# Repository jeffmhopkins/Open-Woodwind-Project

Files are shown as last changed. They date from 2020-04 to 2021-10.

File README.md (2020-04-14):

# Open-Woodwind-Project

The Open Woodwind Project is aimed at making an open source MIDI Woodwind Controller with onboard synthesizer.

It utilizes a Teensy microcontroller with Audio Breakout, two MPR121s,BNO055 IMU, and MPXV4006GP pressure Transducer. 

OWP_Synth is a sub project utilizing a Teensy Audio Libray based multi oscillator with LFOs, waveshaping, effects, and a complex modulation scheme, controlled over an OSC iPad interface. It will eventually be fully integrated into the onboard synth for the controller.  

The OWP_Synth relies heavily on a TouchOSC interface to control it. This requires an OSC to MIDI bridge. On Windows you can use TouchOSC MIDI bridge, but for linux there's no offering from the TouchOSC developers, so it's a bit more complicated to setup, but all the config files and packages are called out for, and you should be able to get it setup if you want. See https://github.com/jeffmhopkins/Open-Woodwind-Project/tree/master/src/osc_configuration_for_linux_touchosc readme for how to do this.

See https://hackaday.io/project/2992-the-open-woodwind-project for porject log information.

I'll be including source code, and the 3D printing files necessary to reproduce this project in full here.

Jeff

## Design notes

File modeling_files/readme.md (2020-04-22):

# Modeling Files

* Teensy Box - Files for the standalone Teensy 4.0 + Audio Board Rev D
* Instrument - Files for the new OWP instrument

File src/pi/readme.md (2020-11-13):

# Setup Pi for powering on
* Ensure SD card is fully inserted
* Ensure USB Audio interface (the one that came taped to the case) is plugged in to front of Pi (I usually plug it in the middle bottom USB)
* Plug in the Pocket Synth into the front USB
* Plug in your MIDI controller to the front USB
* Plug in the DC power supply to mains voltage
* Plug in the micro USB into the Pi, it’ll start powering on
# Configure iPad
* Power on iPad, ensure you have TouchOSC and VNC installed
* Connect to the ‘OpenSynth’ WiFi network, password is ‘OpenSynth’
* * The WiFi network defaults to DHCP, so IP address should automatically be assigned (in the 10.10.10.X range)
* * It might take a minute to actually connect and assign an IP address, so give it some time.
* Launch VNC and connect to ’10.10.10.10’ username ‘pi’ password ‘OpenSynth’
# Configure Pi
* The Pi uses Jack to control MIDI patching. Once a Patchbay is saved, it will automagically patch your devices as they are plugged in. The Jack control interface is auto launched at power up. 
* Click on ‘Patch Bay’ in the Jack control interface
* Patch your MIDI controller to match the routing of the ‘Open Woodwind’
* SCREENSHOT GOES HERE
* Save the patch bay and make sure it’s ‘active’
# Test setup
* At this point you should be able to play notes and have the MIDI stream into the Pocket Synth, this can be verified with headphones from the OpenSynth headphone output.
# Configure TouchOSC
* You must transfer the TouchOSC interface to the iPad. File can be found here: https://github.com/jeffmhopkins/Open-Woodwind-Project/blob/master/src/osc_configuration_for_linux_touchosc/osc2midi.omm
* In TouchOSC configure the interface to connect to send OSC messages to 10.10.10.10:3333 and listen on port 3334
# At this point the TouchOSC interface on the iPad should be receiving OSC messages from the Pi. Breath, etc should be visibly changing with your controller values.
* Play and have fun controlling the Synth from the TouchOSC interface
# Shutdown the Pi
* Log into pi via VNC, hit the main menu button and ‘shutdown’
* If you just unplug the USB power, it will work, but you risk corrupting the SD card (I’ve not had this happen even multiple ‘hard shutdowns’ but I try to not to do it)

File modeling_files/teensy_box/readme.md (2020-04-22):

# Files for a box to hold the Teensy 4.0 + Audio Boad Rev D

Notes:
* The Teensy is meant to be soldered directly to the top of the audio board, using male pin headers. One of the capacitors on the Teensy comes VERY close to the SD card slot. Insulate the top of the SD card slot with kapton tape to avoid shorting.
* The Audio board is secured to the box with three 6mm M3 screws. The board fits TIGHT to the interior of the box. You have to insert the USB and headphone jack, and press fit it down into the box.
* If the board is too tight, you may have to inset the model in your slicer (My printer and your printer are likely a little different)
* The bumper is meant to be printed with the modeled supports in TPU. The modeled supports have a 0.3mm gap, which when you slice should be a ONE LAYER gap. adjust your settings to make this true, and your supports will come out great.

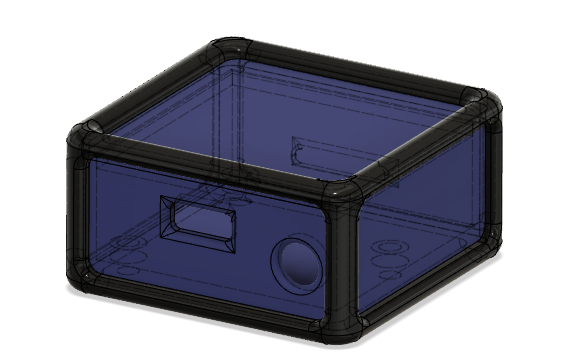
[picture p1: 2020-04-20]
modeling_files/teensy_box/Box.PNG

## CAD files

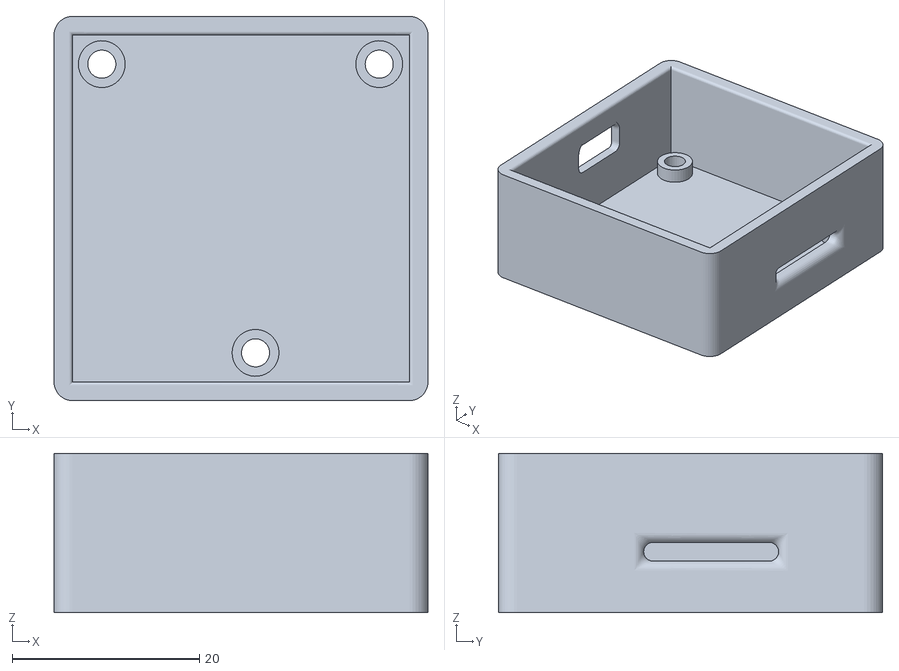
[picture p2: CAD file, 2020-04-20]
modeling_files/teensy_box/Teensy_Box_Box.stl
39.9 x 41.0 x 17.0

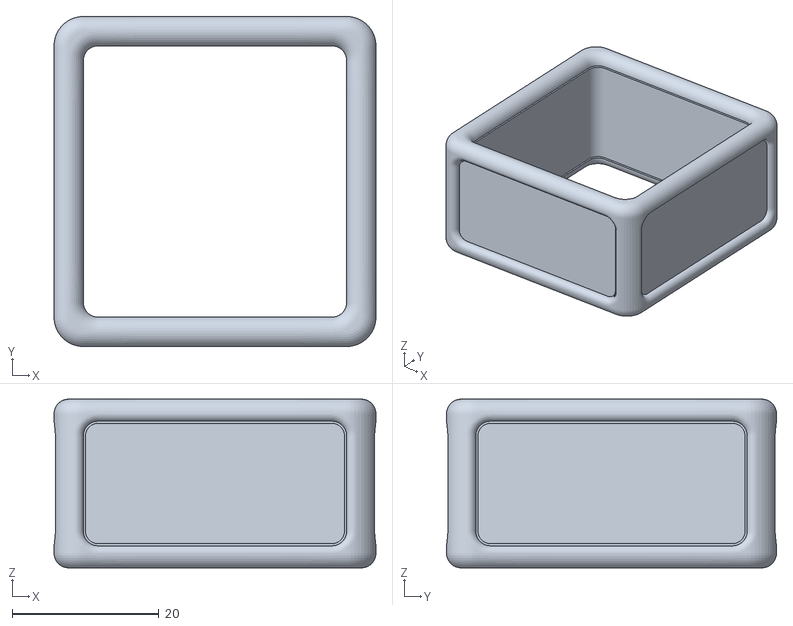
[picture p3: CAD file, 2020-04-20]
modeling_files/teensy_box/Teensy_Box_Bumper_With_Supports.stl
43.9 x 45.0 x 23.0

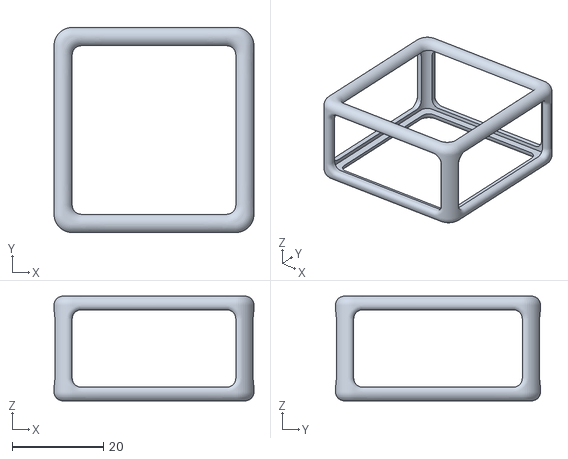
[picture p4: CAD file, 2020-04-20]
modeling_files/teensy_box/Teensy_Box _Bumper_No_Supports.stl
43.9 x 45.0 x 23.0

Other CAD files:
modeling_files/instrument.f3d

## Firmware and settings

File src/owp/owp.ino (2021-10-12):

/*
    This program is free software: you can redistribute it and/or modify
    it under the terms of the GNU General Public License as published by
    the Free Software Foundation, either version 3 of the License, or
    (at your option) any later version.
    This program is distributed in the hope that it will be useful,
    but WITHOUT ANY WARRANTY; without even the implied warranty of
    MERCHANTABILITY or FITNESS FOR A PARTICULAR PURPOSE.  See the
    GNU General Public License for more details.
    You should have received a copy of the GNU General Public License
    along with this program.  If not, see <https://www.gnu.org/licenses/>.
*/


/*

The Open Woodwind Project uses the following components:
  Teensy 3.2
  MPR121 (address 0x5A)
  MPR121 (address 0x5B)
  MPX2010GS (going into A0, a few filtering caps installed)
  BNO055
  
  It should be compiled in the Teensy Arduino environment with MIDI + SERIAL board options.

*/

#include <Wire.h>
#include <SPI.h>
#include "Adafruit_MPR121.h"
#include <Adafruit_Sensor.h>
#include <Adafruit_BNO055.h>
#include <utility/imumaths.h>

#define STATE_NOTE_OFF 0
#define STATE_NOTE_NEW 1
#define STATE_NOTE_ON  2

#define SETTINGS_NOTE_DEBOUNCE_DELAY 20
#define SETTINGS_BREATH_AVERAGING    0.7f
#define SETTINGS_BREATH_GAIN         3.0f
#define SETTINGS_BREATH_THRESHOLD    225
#define SETTINGS_CC_DELAY            0
#define SETTINGS_LEGATO              true
#define SETTINGS_TOUCH_LEVEL         100

#define IMU_RAISE  0
#define IMU_LOWER  1
#define IMU_CENTER 2
#define IMU_CC_POSITIVE false
#define IMU_CC_NEGATIVE true

#define CONTROLLER_MODE_MIDI    0
#define CONTROLLER_MODE_MODULAR 1
#define CONTROLLER_MODE_TRIGGER 2
#define CONTROLLER_SET_CCW_OFF  3
#define CONTROLLER_SET_CCW_EXPRESSION 4
#define CONTROLLER_SET_MOD_WHEEL_OFF 5
#define CONTROLLER_SET_MOD_WHEEL_ON  6
#define CONTROLLER_SET_BREATH_ON 7
#define CONTROLLER_SET_BREATH_OFF 8

#define CCW_MODE_OFF        0
#define CCW_MODE_EXPRESSION 1

int trigger_min_velocity = 10;

int state = STATE_NOTE_OFF;

int  note_temp              = 0;                    //Temporary variable used during legato fingering 
int  note_playing           = 0;                    //The MIDI note of the current note being played
int  note_fingered          = 0;                    //The MIDI note of the current note being fingered
bool note_debounce          = false;                //Whether or not we are in debounce wait
long note_debounce_time     = 0;                    //The millis() at time of finger change, start of debounce 
int  note_fingered_debounce = 0;                    //The MIDI note of the current note being fingered during debounce wait
int  note_debounce_delay    = SETTINGS_NOTE_DEBOUNCE_DELAY; //How long to wait in debounce before committing to finer change

int   breath_sent      = 0;                         //The last CC breath message value
int   breath_measured  = 0;                         //Current measured breath
float breath_averaging = SETTINGS_BREATH_AVERAGING; //Percent of new vs old breath
int   breath_threshold = SETTINGS_BREATH_THRESHOLD; //The threshold for breath to trigger a note
long  breath_time      = 0;                         //The millis() at time of threshold breach
int   breath_risetime  = 5;                         //the delay after threshold breach before sampling breath for the first CC message

long  cc_time  = 0;                                 //The millis() at time of last CC send
int   cc_delay = SETTINGS_CC_DELAY;                 //Delay in ms between CC messages

bool  legato = SETTINGS_LEGATO;                     //Legato fingering mode

float deg_y           = 0.0;                        //The angle of the instrument
float deg_y_averaging = 0.5;                        //Smoothing from last loop's poll

float deg_z           = 0.0;                        //The roll of the instrument
float deg_z_averaging = 0.5;                        //Smoothing from last loop's poll

float accel           = 0.0;		                    //Accelerometer data
float accel_averaging = 0.5;                        //Smoothing from last loop's poll
float accel_damping   = 1.5;		                    //Accelerometer dampening

float imu_deg_init    = 0.0;                        //Placeholder for when we gate our pb buttons, locking in the current instrument angle 
float imu_up_limit    = -40;		                    //The up angle for modulation
float imu_down_limit  = -60;		                    //The down angle for modulation

float imu_roll_deadband    = 25;			              //How wide our roll dead band is
float imu_roll_upper_limit = 30;	                  //Upper roll limit
float imu_roll_lower_limit = -30;		                //Lower roll limit
boolean imu_roll_active    = false;		              //Is imu roll active

float imu_pb_deg_init   = 0.0;						
float imu_pb_up_limit   = 15;
float imu_pb_down_limit = -15;
float imu_pb_deadband   = 6.0;
bool  imu_pb_active     = false;

bool  settings_mode_fingered = false;
int   controller_return_mode = 0;


//THESE ARE THE DEFAULT SETTINGS
int   controller_mode = CONTROLLER_MODE_MODULAR;
int   ccw_mode = CCW_MODE_OFF; //CCW_MODE_EXPRESSION
bool  mod_wheel_enabled = true;
bool  breath_enabled = false; //when setting to midi mode this comes on automatically, and modular turns it off

Adafruit_MPR121 touchA = Adafruit_MPR121();	      //Actual MPR121 object
Adafruit_MPR121 touchB = Adafruit_MPR121();			
Adafruit_BNO055 bno = Adafruit_BNO055(55);	      //IMU	
sensors_event_t event;				                    //IMU event object

bool A[] = {false,false,false,false,false,false,false,false,false,false,false,false}; // These are the arrays for finger positions
bool B[] = {false,false,false,false,false,false,false,false,false,false,false,false};

bool A_last[] = {false,false,false,false,false,false,false,false,false,false,false,false}; // These are the arrays for finger positions
bool B_last[] = {false,false,false,false,false,false,false,false,false,false,false,false};

long A_debounce[] = {0,0,0,0,0,0,0,0,0,0,0,0};
long B_debounce[] = {0,0,0,0,0,0,0,0,0,0,0,0};

int CC[128]; 					      //CC array
int pb = 0;					        //pb value

const int ledPin = 13;			//LED for noteOn (onboard Teensy)

float ambient_breath_reading = 0;


void setup() {
  for(int i = 0; i < 128; i++) {
    CC[i] = 0;
  }
  touchA.begin(0x5A);
  touchB.begin(0x5B);
  if(!bno.begin())
  {
    /* There was a problem detecting the BNO055 ... check your connections */
    Serial.print("Ooops, no BNO055 detected ... Check your wiring or I2C ADDR!");
    while(1);
  }
  delay(1000);
  bno.setExtCrystalUse(true);
  pinMode(ledPin, OUTPUT);

  ambient_breath_reading = SETTINGS_BREATH_GAIN * analogRead(A0);
  if(ambient_breath_reading > 1023) ambient_breath_reading = 1023;
}
  
void loop() {
  // Update our breath, fingered note, and CC messages
  updateSensors();
  if(cc_delay == 0) {
    sendCC();
  } else {
    if(millis() > cc_time + cc_delay) {
      sendCC();
      cc_time = millis();
    }
  }
  //Check for settings beings changed
  if(controller_mode == CONTROLLER_SET_CCW_OFF)        {ccw_mode = CCW_MODE_OFF;        controller_mode = controller_return_mode;}
  if(controller_mode == CONTROLLER_SET_CCW_EXPRESSION) {ccw_mode = CCW_MODE_EXPRESSION; controller_mode = controller_return_mode;}
  if(controller_mode == CONTROLLER_SET_MOD_WHEEL_ON)   {mod_wheel_enabled = true;       controller_mode = controller_return_mode;}
  if(controller_mode == CONTROLLER_SET_MOD_WHEEL_OFF)  {mod_wheel_enabled = false;      controller_mode = controller_return_mode;}
  if(controller_mode == CONTROLLER_SET_BREATH_ON)      {breath_enabled    = true;       controller_mode = controller_return_mode;}
  if(controller_mode == CONTROLLER_SET_BREATH_OFF)     {breath_enabled    = false;      controller_mode = controller_return_mode;}

  //Change Controller Modes, or goto the current 
  if(controller_mode == CONTROLLER_MODE_MIDI) {
    if(controller_return_mode != CONTROLLER_MODE_MIDI) breath_enabled = true;  
    stateMachineControllerMidi();   
  }
  if(controller_mode == CONTROLLER_MODE_MODULAR) {
    if(controller_return_mode != CONTROLLER_MODE_MODULAR) breath_enabled = false; 
    stateMachineControllerModular();
  }
  if(controller_mode == CONTROLLER_MODE_TRIGGER) {
    stateMachineControllerTrigger();
  }
  
  while (usbMIDI.read()) {
    // ignore incoming messages
  }
}

void stateMachineControllerMidi() {
    if(state == STATE_NOTE_OFF) {
      if(breath_measured > breath_threshold) {
        breath_time = millis();
        state = STATE_NOTE_NEW;
      }
    }
    if(state == STATE_NOTE_NEW) {
      if(settings_mode_fingered) {
        setSettings();
      } else {
         if(breath_measured > breath_threshold) {
           if(millis() > breath_time + breath_risetime) {
             sendCC();
             sendNoteOn(note_fingered);
             cc_time = millis();
             digitalWrite(ledPin, HIGH);
             state = STATE_NOTE_ON;
          }
        } else {
          state = STATE_NOTE_OFF;
        }
      }
    }
    if((state == STATE_NOTE_ON) & (!settings_mode_fingered)) {
      if(breath_measured > breath_threshold) {
        if(note_fingered != note_playing) {
          if(legato) {
            note_temp = note_playing;
            if(imu_pb_active) {
              imu_pb_deg_init = deg_y;
              usbSendPitchBend(0, 1);
            }
            sendNoteOn(note_fingered);
            sendNoteOff(note_temp);
          } else {
            sendNoteOff(note_playing);
            sendNoteOn(note_fingered);
          }
        }
      } else {
        if(!settings_mode_fingered) {
          sendNoteOff(note_playing);
          digitalWrite(ledPin, LOW);
          state = STATE_NOTE_OFF;
        }
      }
    }
}

void stateMachineControllerModular() {
  if(settings_mode_fingered) {
    updateBreath();
    if(breath_measured > breath_threshold) {
      setSettings();
    } 
  } else {
    if(note_fingered != note_playing) {
      if(legato) {
        note_temp = note_playing;
        if(imu_pb_active) {
          imu_pb_deg_init = deg_y;
          usbSendPitchBend(0, 1);
        }
        sendNoteOn(note_fingered);
        sendNoteOff(note_temp);
      } else {
        sendNoteOff(note_playing);
        sendNoteOn(note_fingered);
      }
    }
  }
}

void stateMachineControllerTrigger() {
  int b = map(breath_measured,SETTINGS_BREATH_THRESHOLD,1023,0,127);
  float d= deg_y;
  if(d < imu_down_limit) d = imu_down_limit;
  if(d > imu_up_limit)   d = imu_up_limit;
  int velocity = (int)mapf(d, imu_down_limit, imu_up_limit, trigger_min_velocity, 127);
   
  if(b>64) {
    if(B[0] & !B[1] & B[2]) {
      settings_mode_fingered = true;
    } else {
      settings_mode_fingered = false;
    }
    if(settings_mode_fingered) {
      setSettings();
    }
  }
  for (uint8_t i=0; i<12; i++) {
    A_last[i] = A[i];
    B_last[i] = B[i];
    A[i] = touchA.filteredData(i) < SETTINGS_TOUCH_LEVEL;
    B[i] = touchB.filteredData(i) < SETTINGS_TOUCH_LEVEL;
  }
  int trigger_offset = 0;
  if( B[0] &!B[1])         trigger_offset -= 24;  // bottom left
  if( B[0] & B[1])         trigger_offset -= 12;  // bottom left mid left bridged
  if( B[1] & B[2])         trigger_offset += 12;  // mid left top left bridged
  if(!B[1] & B[2])         trigger_offset += 24;  // top left
  for(int i = 0; i < 12; i++) {
    //bass drum on 36
    if(A_last[i] != A[i]) A_debounce[i] = millis() + 10;
    if((millis() > A_debounce[i]) && A_debounce[i] != 0) {
       if(!A[i]) sendNoteOff(36 + i + trigger_offset);
       if(A[i])  sendNoteOn(36 + i + trigger_offset, velocity);
       A_debounce[i] = 0;
    }
  }
  
}

void setSettings() {
   if(A[0]) controller_mode = CONTROLLER_MODE_MIDI;    // A[0] = Left Hand Index
   if(A[1]) controller_mode = CONTROLLER_MODE_MODULAR; // A[1] = Left Hand Middle
   if(A[2]) controller_mode = CONTROLLER_MODE_TRIGGER; // A[2] = Left Hand Ring
   if(A[3]) {controller_return_mode = controller_mode; controller_mode = CONTROLLER_SET_CCW_OFF;}
   if(A[4]) {controller_return_mode = controller_mode; controller_mode = CONTROLLER_SET_CCW_EXPRESSION;}
   if(A[5]) {controller_return_mode = controller_mode; controller_mode = CONTROLLER_SET_MOD_WHEEL_OFF;}
   if(A[6]) {controller_return_mode = controller_mode; controller_mode = CONTROLLER_SET_MOD_WHEEL_ON;}
   if(A[7]) {controller_return_mode = controller_mode; controller_mode = CONTROLLER_SET_BREATH_OFF;}
   if(A[8]) {controller_return_mode = controller_mode; controller_mode = CONTROLLER_SET_BREATH_ON;}
   
         // A[5] = Right Hand Index
         // A[6] = Right Hand Middle
         // A[7] = Right Hand Ring
}

void updateSensors() {
  updateBreath();
  if(controller_mode != CONTROLLER_MODE_TRIGGER) updateNote();
  updateCC();
}

void updateBreath() {
  float value = SETTINGS_BREATH_GAIN * analogRead(A0);
  if(value>1023) value = 1023;
  breath_measured = value; //breath_averaging * value + (1.0f - breath_averaging) * breath_measured;
}

void updateNote() {
  note_fingered_debounce = 60 + parseNote(); //Update from capacitive touch board
  if(note_fingered_debounce != note_fingered) {
    if(note_debounce) {
      if(millis() > note_debounce_time + note_debounce_delay) {
        note_fingered = note_fingered_debounce;
        note_debounce = false;
      }
    } else {
      note_debounce_time = millis();
      note_debounce = true;
    }
  }
}

int parseNote() {
	// Mapping as follows: 
	// A[0] = Left Hand Index
	// A[1] = Left Hand Middle
	// A[2] = Left Hand Ring
	// A[3] = Left Hand Pinky 1 (sharp)
	// A[4] = Left Hand Pinky 2 (flat)
	// A[5] = Right Hand Index
	// A[6] = Right Hand Middle
	// A[7] = Right Hand Ring
	// A[8] = Right Hand Pinky 1 (Sharp)
	// A[9] = Right Hand Pinky 2 (Flat)
	// A[10]= Right Hand Pinky 3 (Double Flat)
	// B[0] = Bottom Octave (Left thumb bottom)
	// B[1] = Middle Octave (Left thumb mid)
	// B[2] = Top Octave    (Left thumb top)
	// B[3] = PB gate 
	// B[4] = PB gate
	// B[5] = PB Gate
	//
  for (uint8_t i=0; i<12; i++) {
    A[i] = touchA.filteredData(i) < SETTINGS_TOUCH_LEVEL;
    B[i] = touchB.filteredData(i) < SETTINGS_TOUCH_LEVEL;
  }

  //Check Settings mode
  if(B[0] & !B[1] & B[2]) {
    settings_mode_fingered = true;
  } else {
    settings_mode_fingered = false;
  }

  //Determine Register
  bool rh = !A[0] & A[1] & !A[2] & A[5];
  bool rl = !A[5] & A[6] &  A[7] & A[10];
  bool rm = !rh & !rl;

  int note = 13;

  if(rm) {
    if( A[0] & !A[1]) note -= 2;
    if(!A[0] &  A[1]) note -= 1;
    if( A[0] &  A[1]) note -= 4;
    if(A[2]) note -= 2;
    if(A[5]) note -= 2;
    if(A[6]) note -= 1;
    if(A[7]) note -= 2;
  }
  if(rh) {
    note = 17;
    if(A[6]) note -= 1;
    if(!A[5] & A[6]) note += 2;
    if(A[7]) note -= 2;
  }
  if(rl) {
     note = 3;
     if(A[0] & !A[1]) note -= 2;
     if(!A[0] & A[1]) note -= 1;
     if(A[0] & A[1]) note -= 4;
     if(A[2]) note -= 2;
     if(A[5]) note -= 2;
  }
  if(A[3]) note += 1;
  if(A[4]) note -= 1;
  if(A[8]) note += 1;
  if(A[9]) note -= 1;
  if(A[10]) note -= 2;

  //Alt Bb
  if(A[0] & !A[1] & !A[2] & A[5]) note += 1;

  //octaves
  if( B[0] &!B[1])                 note -= 24;  // bottom left
  if( B[0] & B[1])                 note -= 12;  // bottom left mid left bridged
  if(!B[0] & B[1] & !B[2] & !B[4]) note = note; // mid left
  if( B[1] & B[2])                 note += 12;  // mid left top left bridged
  if(!B[1] & B[2])                 note += 24;  // top left

  if(B[3] || B[4] || B[5]) { //If our pitch bend gates are active
    if(!imu_pb_active) {
      imu_pb_active = true;
      imu_pb_deg_init = deg_y;
    }
  }
  
  if(!(B[3] || B[4] || B[5])) {
    imu_pb_active = false;
  }
  
  return note;
}

void sendNoteOn(int note) {
  note_playing = note;
  usbMIDI.sendNoteOn(note, 127, 1);
}

void sendNoteOn(int note, int velocity) {
  note_playing = note;
  usbMIDI.sendNoteOn(note, velocity, 1);
}

void sendNoteOff(int note) {
  usbMIDI.sendNoteOff(note, 0, 1);
}

void sendCC() {
    if(controller_mode != CONTROLLER_MODE_TRIGGER) {
      if(mod_wheel_enabled) sendCC_modulation();
      if(breath_enabled)    sendCC_breath();
      sendCC_pitchbend();
    }
}

void sendCC_breath() {
  if(CONTROLLER_MODE_MIDI) {
    int b = 0;
    if(state == STATE_NOTE_ON) {
      if(breath_measured < SETTINGS_BREATH_THRESHOLD) breath_measured = SETTINGS_BREATH_THRESHOLD;
      b = map(breath_measured,SETTINGS_BREATH_THRESHOLD,1023,0,127);
    }
    usbSendControlChange(2, b, 1); //Breath
    breath_sent = b;
  } else {
    if((breath_measured - ambient_breath_reading) < 0) {
      usbSendControlChange(2, 0, 1);
    } else {
      usbSendControlChange(2, map(breath_measured,ambient_breath_reading,1023,0,127), 1);
    }
  }

}

void sendCC_pitchbend() {
  //Pitch bend is pretty messy.... so stay with me here. A lot of mapping, and limits.	
  //In updateCC() we poll our IMU data.
	
  float aa = accel; //aa is now a working copy of the accel value
  float c = 0;      //c is the value that will be send out (the pb value itself)
  
  if(aa > 10) aa = 10; //We limit the raw accel value to +/- 10 for easy mapping, and reasonable limits
  if(aa < -10) aa = -10;
  
  float a = mapf(aa, -10*accel_damping, 10*accel_damping, -8192, 8192); // map it to pb limits, including our dampening values from settings.

  float u = deg_z; //this is again a working copy from the IMU poll, this is the roll value
  float g = 0;     //g is a placeholder for if we are using a CCW pitchbend up
  
  if(u < imu_roll_lower_limit) u = imu_roll_lower_limit; //put the raw deg_z into out limits
  if(u > imu_roll_upper_limit) u = imu_roll_upper_limit;
  
  if(u > imu_roll_deadband/2) { //If we are outside of our rolldeadband we can send some values
    
	//I currently have it sending expression data instead of pitchbend up, when CCW is beyond the deadband.
	
	//CCW Pitchbend Up
    // g = (int)mapf(u, imu_roll_deadband/2, imu_roll_upper_limit, 0, 8192);
    
     
     //CCW Expression
     if(ccw_mode == CCW_MODE_EXPRESSION) usbSendControlChange(11, mapf(u, imu_roll_deadband/2, imu_roll_upper_limit, 0, 127), 1);
     
  } else { 
    //still within the deadband, so ensure we are sending expression value of 0
    //CCW Expression
    
    if(ccw_mode == CCW_MODE_EXPRESSION) usbSendControlChange(11, 0, 1);
  }
  
  //if we are outside the deadband, map it to pitchbend up/down. This allows for accel shakes inside the deadband to self center, but longer angle changes do full pitch bends.
  if(u < -(imu_roll_deadband/2)) g = (int)mapf(u, -imu_roll_deadband/2, imu_roll_lower_limit, 0, -8192);
  
  
  //If we have our pb gates active
  if(imu_pb_active) {
      float d= deg_y;
      float b = 0;
      
      if(d < imu_pb_deg_init + imu_pb_down_limit) d = imu_pb_deg_init + imu_pb_down_limit;
      if(d > imu_pb_deg_init + imu_pb_up_limit)   d = imu_pb_deg_init + imu_pb_up_limit;
    
      if(d > (imu_pb_deg_init + imu_pb_deadband / 2)) {
         b = mapf(d, imu_pb_deg_init + (imu_pb_deadband / 2), imu_pb_deg_init + imu_pb_up_limit, 0, 8192);
      }
      
      if(d < (imu_pb_deg_init + imu_pb_deadband / 2)) {
         b = mapf(d, imu_pb_deg_init + imu_pb_down_limit,imu_pb_deg_init - (imu_pb_deadband / 2), -8192, 0);
      }
      if((d > (imu_pb_deg_init - imu_pb_deadband / 2)) & (d < (imu_pb_deg_init + imu_pb_deadband / 2))) b = 0;

      c = b - a + g; //cc value = bend angle - accelerometer + roll values
      
      if(c >  8192) c = 8192;
      if(c < -8192) c = -8192;
      usbSendPitchBend((int)c, 1);
      
    } else {
      c = g; //If we're note pb gates active, just use roll values
      if(c >  8192) c = 8192;
      if(c < -8192) c = -8192;
      usbSendPitchBend((int)g, 1);
    }
}

void sendCC_modulation() {
    float d= deg_y;
    if(d < imu_down_limit) d = imu_down_limit;
    if(d > imu_up_limit)   d = imu_up_limit;
    
    usbSendControlChange(1, (int)mapf(d, imu_down_limit, imu_up_limit, 0, 127), 1); //deg

}

void updateCC() {
  //Get instrument Angle in x and y axis
  bno.getEvent(&event);
  deg_y = deg_y_averaging*deg_y + (1.0-deg_y_averaging)*(event.orientation.y);
  deg_z = deg_z_averaging*deg_z + (1.0-deg_z_averaging)*(event.orientation.z);

  //Get instrument acceleration in z axis
  accel = accel_averaging*accel + (1.0-accel_averaging)*(bno.getVector(Adafruit_BNO055::VECTOR_LINEARACCEL).z());
}

float mapf(float x, float in_min, float in_max, float out_min, float out_max) {
  return (x - in_min) * (out_max - out_min) / (in_max - in_min) + out_min;
}

void usbSendControlChange(int cc, int value, int channel) {
  if(CC[cc] != value) {
    usbMIDI.sendControlChange(cc, value, channel);
    CC[cc] = value;
  }
}

void usbSendPitchBend(int value, int channel) {
  if(pb != value) {
    usbMIDI.sendPitchBend(value, channel);
    pb = value;
  }
}

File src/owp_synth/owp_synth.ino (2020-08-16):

/*
 * The Open Woodwind Project - OWP_Synth for Woodwind Controllers by Jeff Hopkins
 * 
 * =============================================================================================================================================
 * 
 * The OWP_Synth is a MIDI synthesizer that runs on a Teensy 4.0 + Audio Shield Rev.D, specially designed for working with the OWP controller.
 * It will eventually also run the controller software on top of the synth, but for now it's standalone.
 * 
 * It's meant to be controlled via the OSC interface on an iPad, and uses an SD card from the Audio Shield to store patches and backing tracks.
 * 
 * Some features:
 *     -Four Oscillators
 *     -Two LFOs
 *     -Six cascaded and mixed overdrive waveform shapers
 *     -LOTS of modulation settings
 *     -Flange, String Chorus, Delay and Reverb effects
 *     
 * =============================================================================================================================================
 * 
 * https://github.com/jeffmhopkins/Open-Woodwind-Project
 * https://hackaday.io/project/2992-the-open-woodwind-project
 * 
 * I created a TouchOSC interface that controls this synth.
 * See https://github.com/jeffmhopkins/Open-Woodwind-Project/tree/master/src/osc_configuration_for_linux_touchosc
 * 
 * I run an osc2midi and midi2osc bridge on a linux box for the mapping. 
 * https://github.com/jeffmhopkins/Open-Woodwind-Project/tree/master/src/osc_configuration_for_linux_touchosc
 * 
 * You can easily create custom OSC interfaces for your setup with ease, just look at the CC mapping below.
 * 
 * You can view the signal routing of the synth by going to https://www.pjrc.com/teensy/gui/index.html and
 * loading in the auto generated portion of the audio library patching below.
 * 
 * =============================================================================================================================================
 * 
 * Basic layout for this project:
 *     owp_synth.ino       -   Main file for the project. 
 *     driven_waveform.ino - Stores the waveform shaper structs
 *     name.c              - creates the USB name of the synth
 *     patches.ino         - handles creatings, loading and saving patch files to the SD card
 *     process_midi        - processes the MIDI messegages coming in for CC based synth settings
 * 
 * =============================================================================================================================================
 * 
 * TODO LIST:
 *   1. Rebumber the CC channels. This would be nice to group similar things together. It'd require remapping in patches.ino, and then updating
 *      the OSC interface to reflect
 *      
 *      This includes remapping portamento amount, volume, reverb etc to standard numbers.
 *      
 *   3. Go through and standardize the CC #define names to the global variable names. They are 95% identintical, but hey should be 100%.
 *   
 *   4. Add another Chorus effect that doesn't have the string quality? Modify number of voices and time block allowance
 *   
 *   5. Branch and merge OWP and OWP_Synth into OWP_Controller_Synth
 *   
 *   https://roboticsbackend.com/arduino-object-oriented-programming-oop/
 * 
 */
#if !defined(ARDUINO_TEENSY40)
  #error "Please Select Teensy 4.0 Board Type"
#endif
 
#if !defined(USB_MIDI) && !defined(USB_MIDI_SERIAL)
  #error "USB MIDI not enabled. Please set USB type to 'Serial + MIDI'."
#endif

#define DEBUG_TO_SERIAL true

#include <Audio.h>
#include <Wire.h>
#include <SPI.h>
#include <SD.h>
#include <SerialFlash.h>
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

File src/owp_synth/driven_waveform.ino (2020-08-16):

/*
 * The Open Woodwind Project - OWP_Synth for Woodwind Controllers by Jeff Hopkins
 * 
 * =============================================================================================================================================
 * 
 * These are the overdrive waveforms, a slightly amplified and clipped wavform to give warm saturation
 * 
 * We can add up to six waveform distortions and add them to each of the six overdrives.
 * 
 * You can plot these in excel to the responses. They go from -1 to 1
 * 
 */

// Some tube input stage response curves sourced from TeensyDist (https://github.com/jcugnoni/TeensyDist) who sourced from Guitarix tables (http://guitarix.org) => THANKS !! 
// inverted and resampled for Teensy Audio Lib - AudioEffectWaveshaper (-1.0 - 1.0 513 samples)

const float wave_shape_tube_12at7[513]       = {-0.7878252,-0.7845943,-0.7813367,-0.7780526,-0.7747419,-0.771405,-0.7680417,-0.7646523,-0.7612367,-0.7577952,-0.7543278,-0.7508345,-0.7473155,-0.7437709,-0.7402008,-0.7366052,-0.7329844,-0.7293385,-0.7256674,-0.7219714,-0.7182505,-0.7145048,-0.7107343,-0.7069392,-0.7031196,-0.6992757,-0.6954075,-0.6915152,-0.6875988,-0.6836584,-0.6796942,-0.6757062,-0.6716946,-0.6676593,-0.6636004,-0.6595184,-0.6554129,-0.6512844,-0.6471328,-0.6429582,-0.6387607,-0.6345405,-0.6302976,-0.6260321,-0.621744,-0.6174334,-0.6131006,-0.6087456,-0.6043684,-0.5999693,-0.5955482,-0.5911052,-0.5866405,-0.582154,-0.577646,-0.5731163,-0.5685652,-0.5639927,-0.5593991,-0.5547842,-0.5501482,-0.5454913,-0.5408133,-0.5361145,-0.531395,-0.5266545,-0.5218935,-0.5171119,-0.5123098,-0.5074872,-0.5026444,-0.4977812,-0.4928978,-0.4879943,-0.4830708,-0.4781271,-0.4731635,-0.4681799,-0.4631765,-0.4581534,-0.4531106,-0.4480482,-0.4429661,-0.4378646,-0.4327435,-0.4276031,-0.4224433,-0.417264,-0.4120656,-0.4068479,-0.4016111,-0.3963552,-0.3910803,-0.3857863,-0.3804734,-0.3751416,-0.3697909,-0.3644212,-0.3590328,-0.3536256,-0.3481997,-0.3427552,-0.337292,-0.3318102,-0.3263099,-0.320791,-0.3152537,-0.3096979,-0.3041236,-0.2985308,-0.2929197,-0.2872903,-0.2816426,-0.2759765,-0.2702923,-0.2645898,-0.258869,-0.2531301,-0.247373,-0.2415976,-0.2358041,-0.2299925,-0.2241628,-0.2183151,-0.2124492,-0.2065654,-0.2006634,-0.1947435,-0.1888055,-0.1828494,-0.1768753,-0.1708832,-0.1648731,-0.158845,-0.152799,-0.1467349,-0.1406529,-0.134553,-0.128435,-0.122299,-0.116145,-0.109973,-0.103783,-0.09757504,-0.09134907,-0.08510508,-0.07884308,-0.07256305,-0.06626499,-0.05994888,-0.05361465,-0.0472623,-0.04089186,-0.03450332,-0.02809666,-0.02167186,-0.01522891,-0.008767786,-0.002288466,0.004209068,0.01072484,0.01725898,0.0238114,0.03038213,0.03697119,0.0435786,0.05020439,0.05684859,0.06351122,0.07019229,0.07689186,0.08360997,0.09034669,0.09710196,0.1038758,0.1106683,0.1174794,0.1243091,0.1311575,0.1380245,0.1449103,0.1518147,0.158738,0.1656799,0.1726406,0.1796199,0.1866178,0.1936344,0.2006695,0.2077231,0.2147952,0.2218855,0.228994,0.2361207,0.2432653,0.2504275,0.2576071,0.2648038,0.2720172,0.279247,0.2864925,0.2937533,0.3010286,0.3083177,0.3156196,0.3229333,0.3302574,0.3375906,0.3449311,0.352277,0.3596261,0.3669758,0.3743232,0.3816651,0.3889975,0.3963161,0.4036163,0.4108926,0.4181389,0.4253488,0.4325148,0.4396291,0.4466833,0.4536682,0.4605743,0.4673913,0.4741094,0.4807185,0.4872088,0.4935706,0.4997948,0.5058734,0.5117989,0.5175653,0.5231676,0.5286018,0.5338652,0.5389574,0.5438786,0.5486302,0.5532144,0.5576344,0.561894,0.5659978,0.5699508,0.5737581,0.5774246,0.5809565,0.5843595,0.5876392,0.5908014,0.5938512,0.5967941,0.5996352,0.6023792,0.6050309,0.6075948,0.6100746,0.6124749,0.6147996,0.6170523,0.6192364,0.6213551,0.6234116,0.6254087,0.6273493,0.6292357,0.6310704,0.6328557,0.6345939,0.636287,0.6379371,0.6395458,0.641115,0.6426462,0.6441411,0.645601,0.6470275,0.6484216,0.6497846,0.651118,0.6524226,0.6536997,0.6549502,0.6561751,0.6573753,0.6585516,0.6597049,0.660836,0.6619455,0.6630343,0.664103,0.6651523,0.6661828,0.6671951,0.6681898,0.6691674,0.6701285,0.6710734,0.6720028,0.672917,0.6738165,0.6747018,0.6755732,0.6764311,0.6772759,0.678108,0.6789277,0.6797354,0.6805313,0.6813158,0.682089,0.6828515,0.6836033,0.6843449,0.6850764,0.6857981,0.6865102,0.687213,0.6879067,0.6885914,0.6892675,0.689935,0.6905942,0.6912453,0.6918885,0.6925239,0.6931517,0.6937721,0.6943853,0.6949914,0.6955904,0.6961826,0.6967682,0.6973472,0.6979198,0.6984862,0.6990464,0.6996006,0.7001489,0.7006914,0.7012283,0.7017595,0.7022852,0.7028056,0.7033207,0.7038307,0.7043356,0.7048355,0.7053306,0.7058208,0.7063063,0.7067872,0.7072635,0.7077353,0.7082028,0.7086659,0.7091247,0.7095795,0.7100301,0.7104766,0.7109192,0.7113579,0.7117927,0.7122238,0.7126511,0.7130747,0.7134948,0.7139112,0.7143242,0.7147338,0.71514,0.7155429,0.7159424,0.7163387,0.7167318,0.7171218,0.7175087,0.7178925,0.7182733,0.7186512,0.7190261,0.7193982,0.7197675,0.7201339,0.7204975,0.7208585,0.7212167,0.7215723,0.7219253,0.7222757,0.7226236,0.722969,0.7233118,0.7236523,0.7239904,0.724326,0.7246593,0.7249903,0.725319,0.7256454,0.7259696,0.7262917,0.7266115,0.7269291,0.7272447,0.7275582,0.7278696,0.7281789,0.7284862,0.7287915,0.7290949,0.7293963,0.7296958,0.7299933,0.730289,0.7305829,0.7308749,0.7311651,0.7314534,0.73174,0.7320248,0.732308,0.7325894,0.7328691,0.7331471,0.7334235,0.7336981,0.7339712,0.7342427,0.7345126,0.7347809,0.7350477,0.7353129,0.7355766,0.7358388,0.7360995,0.7363588,0.7366166,0.7368729,0.7371278,0.7373812,0.7376333,0.737884,0.7381333,0.7383813,0.7386279,0.7388732,0.7391171,0.7393598,0.7396012,0.7398413,0.7400801,0.7403176,0.740554,0.7407891,0.7410229,0.7412556,0.741487,0.7417173,0.7419464,0.7421744,0.7424011,0.7426268,0.7428513,0.7430747,0.743297,0.7435182,0.7437382,0.7439573,0.7441752,0.744392,0.7446079,0.7448227,0.7450364,0.7452492,0.7454609,0.7456716,0.7458813,0.74609,0.7462977,0.7465045,0.7467102,0.7469151,0.747119,0.747322,0.747524,0.7477251,0.7479253,0.7481245,0.7483229,0.7485204,0.748717,0.7489127,0.7491075,0.7493016,0.7494947,0.7496869,0.7498783,0.750069,0.7502587,0.7504476,0.7506357,0.7508231,0.7510096,0.7511953,0.7513802,0.7515643,0.7517477,0.7519303,0.7521121,0.7522931,0.7524734};
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

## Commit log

2020-04-02 Added 3D files for instrument body
    initial commit of instrument 3D model
    [instrument.f3d]
2020-04-05 Commit of the standalone MIDI synth of the Teensy4
2020-04-05 added filter_resonance to CC 76
2020-04-06 Added a multi-oscillator patch
    Simply uncomment out the patch in setup();
    [owp_synth.ino]
2020-04-06 Updated documentation
    CC 75 goes to all four oscillator pulse widths, not just oscillator 1
    [owp_synth.ino]
2020-04-07 TouchOSC file for ipad to control the Teensy Synth
2020-04-10 broke off into new
    makes it easier to read
    [process_midi.ino]
2020-04-12 LFO Phase Reset
    Added phase reset and LFO destination mappings
    [owp_synth.ino, patches.ino, process_midi.ino]
2020-04-12 SD Contents
    Comes with four demo backing tracks (from the Teensy audio demos) and 10 patches
2020-04-13 Overdrive Cascade + Bug fix
    [owp.ino, owp_synth.ino, patches.ino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]
2020-04-13 VCA/Filter Bypass
    Added the VCA and Filter bypass objects in audio routing, CC control still needs added
2020-04-14 Filter type, filter bypass, vca bypass
    Added new CCs to control filter type, added audio devices to allow for filter bypass, vca bypass and filter selection
    Moved #define CC into patch for easier editing and
2020-04-20 Adding Teensy 4.0 Box STL files
    [Teensy_Box _Bumper_No_Supports.stl, Teensy_Box_Box.stl, Teensy_Box_Bumper_With_Supports.stl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]
2020-04-22 Adding audio line in
    Still needs CCs attached
2020-04-25 Bug fix for wave2/3/4 gain and EQ from patch
    [owp_synth.ino, patches.ino, process_midi.ino]
2021-02-15 Commiting LED Controller
    Commiting LED Controller
2021-02-15 quick bug update to LED
    [owp_led_controller.ino]
2021-10-10 New Modes
    Added the following:
    MIDI Mode
    Modular Mode
    Trigger Mode
    Ability to turn off ccw expression and mod wheel via shortcuts
    [owp.ino, owp_led_controller.ino]
2021-10-12 bug fix and added breath on/off
    We can now turn breath on and off in both midi and modular modes.
    Fixed bug where we could only turn on modulation wheel
    [owp.ino]
